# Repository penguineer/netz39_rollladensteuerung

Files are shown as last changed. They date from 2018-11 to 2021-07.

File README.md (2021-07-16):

# Rolladensteuerung

## Content

- controller:       Relais-Controller Rollläden
- manuellsteuerung: Schalter für Manuellbetrieb Rollläden
- raspberry:        Software für den Kontroll-Raspy
- relaiskarte:      Relais Rollläden
- switchboard:      Altes Schalterboard
- tuer-controller:  I2C-Bridge zur Tür-Steuerung
- tuer-steuerung:   Kontrolle Motor und Türstatus-Schalter
- wd-switch:        Watchdog-Switch für Reset per Raspy-

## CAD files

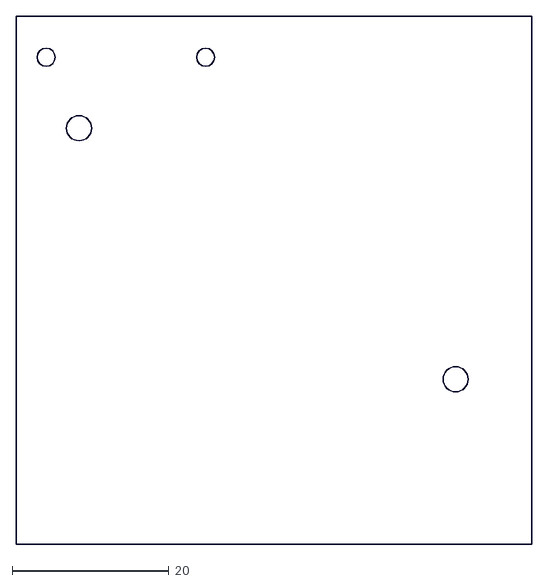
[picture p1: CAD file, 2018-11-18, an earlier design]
tuer-steuerung/converted_old/tuer-steuerung-dim.dxf
65.7 x 67.3

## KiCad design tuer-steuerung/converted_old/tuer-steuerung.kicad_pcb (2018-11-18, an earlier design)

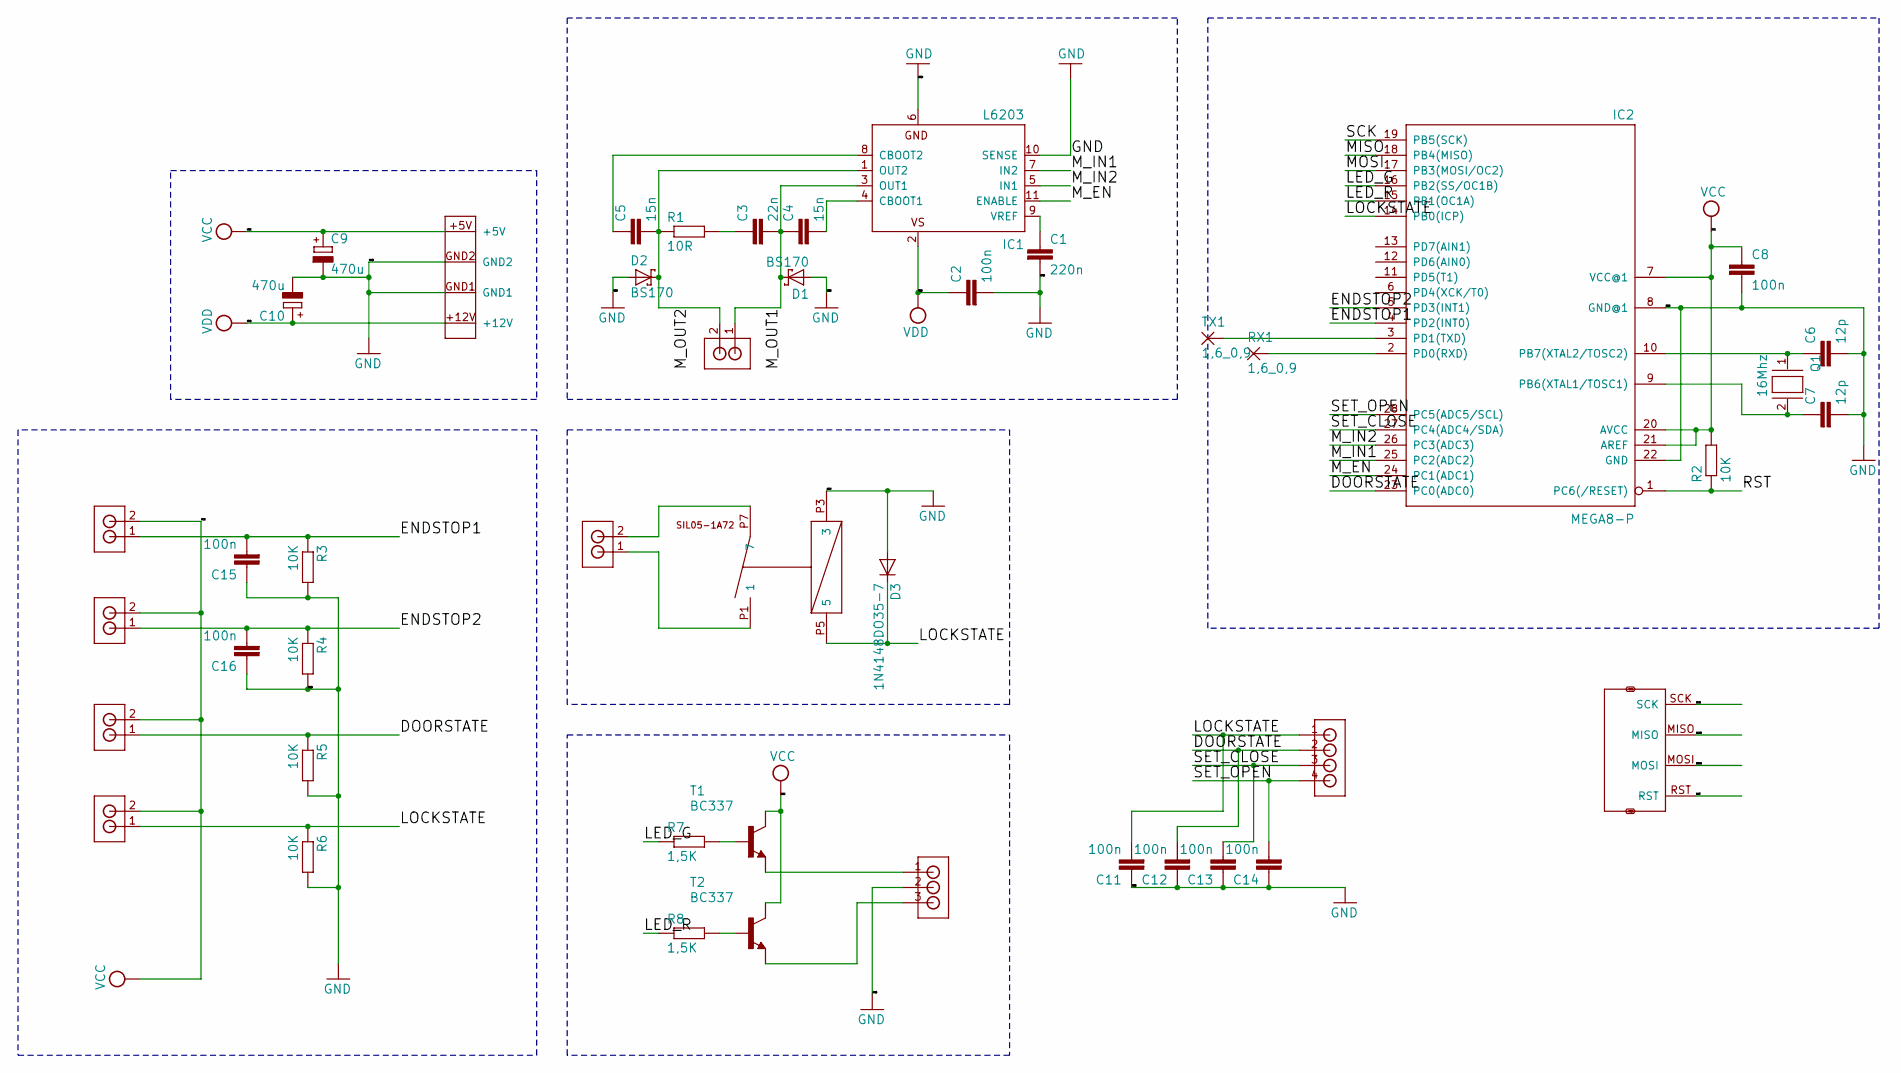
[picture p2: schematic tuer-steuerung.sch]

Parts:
C1: 220n; C025-024X044
C2, C8, C11, C12, C13, C14, C15, C16: 100n; C025-024X044
C3: 22n; C025-024X044
C4: 15n; C025-024X044
C5: 15n; C050-024X044
C6, C7: 12p; C050-025X075
C9, C10: 470u; TAP5-80
D1, D2: BS170; DO35-7
D3: 1N4148DO35-7; DO35-7
DOORSTATE1: RIACON_101_2
ENDSTOP1, ENDSTOP2: RIACON_101_2
IC1: L6203; MULTIWATT-11
IC2: MEGA8-P; DIL28-3
LOCKSTATE1: RIACON_101_2
MOTOR1: RIACON_101_2
NERDSTERN1: RIACON_101_2
Q1: 16Mhz; QS
R1: 10R; 0207_5V
R2, R3, R4, R5, R6: 10K; 0204_5
R7, R8: 1,5K; 0204_5
RX1: 1,6_0,9
T1, T2: BC337; TO92
TX1: 1,6_0,9
U$1: PSW_5
U$2: SIL05-1A72
U$3: AVR_ISP
U$4: RIACON_101_3
U$5: RIACON_101_4

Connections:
/DOORSTATE: C12.2, DOORSTATE1.1, IC2.23 (PC0(ADC0)), R5.1, U$5.2
/ENDSTOP1: C15.2, ENDSTOP1.1, IC2.4 (PD2(INT0)), R3.1
/ENDSTOP2: C16.2, ENDSTOP2.1, IC2.5 (PD3(INT1)), R4.1
/LED_G: IC2.16 (PB2(SS/OC1B)), R7.1
/LED_R: IC2.15 (PB1(OC1A)), R8.1
/LOCKSTATE: C11.2, D3.C, IC2.14 (PB0(ICP)), LOCKSTATE1.1, R6.1, U$2.P5 (5), U$5.1
/MISO: IC2.18 (PB4(MISO)), U$3.MISO
/MOSI: IC2.17 (PB3(MOSI/OC2)), U$3.MOSI
/M_EN: IC1.11 (ENABLE), IC2.24 (PC1(ADC1))
/M_IN1: IC1.7 (IN2), IC2.25 (PC2(ADC2))
/M_IN2: IC1.5 (IN1), IC2.26 (PC3(ADC3))
/M_OUT1: C3.2, C4.1, D1.C, IC1.3 (OUT1), MOTOR1.1
/M_OUT2: C5.2, D2.C, IC1.1 (OUT2), MOTOR1.2, R1.1
/RST: IC2.1 (PC6(/RESET)), R2.1, U$3.RST
/SCK: IC2.19 (PB5(SCK)), U$3.SCK
/SET_CLOSE: C13.2, IC2.27 (PC4(ADC4/SDA)), U$5.3
/SET_OPEN: C14.2, IC2.28 (PC5(ADC5/SCL)), U$5.4
GND: C1.2, C2.2, C6.2, C7.2, C8.2, C9.-, C10.-, C11.1, C12.1, C13.1, C14.1, C15.1, C16.1, D1.A, D2.A, D3.A, IC1.6 (GND), IC1.10 (SENSE), IC2.8 (GND@1), IC2.22 (GND), R3.2, R4.2, R5.2, R6.2, U$1.GND1, U$1.GND2, U$2.P3 (3), U$3.GND, U$4.2
unnamed: C1.1, IC1.9 (VREF)
unnamed: C3.1, R1.2
unnamed: C4.2, IC1.4 (CBOOT1)
unnamed: C5.1, IC1.8 (CBOOT2)
unnamed: C6.1, IC2.10 (PB7(XTAL2/TOSC2)), Q1.1
unnamed: C7.1, IC2.9 (PB6(XTAL1/TOSC1)), Q1.2
unnamed: IC2.2 (PD0(RXD)), RX1.1
unnamed: IC2.3 (PD1(TXD)), TX1.1
unnamed: NERDSTERN1.1, U$2.P1 (1)
unnamed: NERDSTERN1.2, U$2.P7 (7)
unnamed: R7.2, T1.2 (B)
unnamed: R8.2, T2.2 (B)
unnamed: T1.1 (E), U$4.1
unnamed: T2.1 (E), U$4.3
VCC: C8.1, C9.+, DOORSTATE1.2, ENDSTOP1.2, ENDSTOP2.2, IC2.7 (VCC@1), IC2.20 (AVCC), IC2.21 (AREF), LOCKSTATE1.2, R2.2, T1.3 (C), T2.3 (C), U$1.+5V, U$3.VCC
VDD: C2.1, C10.+, IC1.2 (VS), U$1.+12V

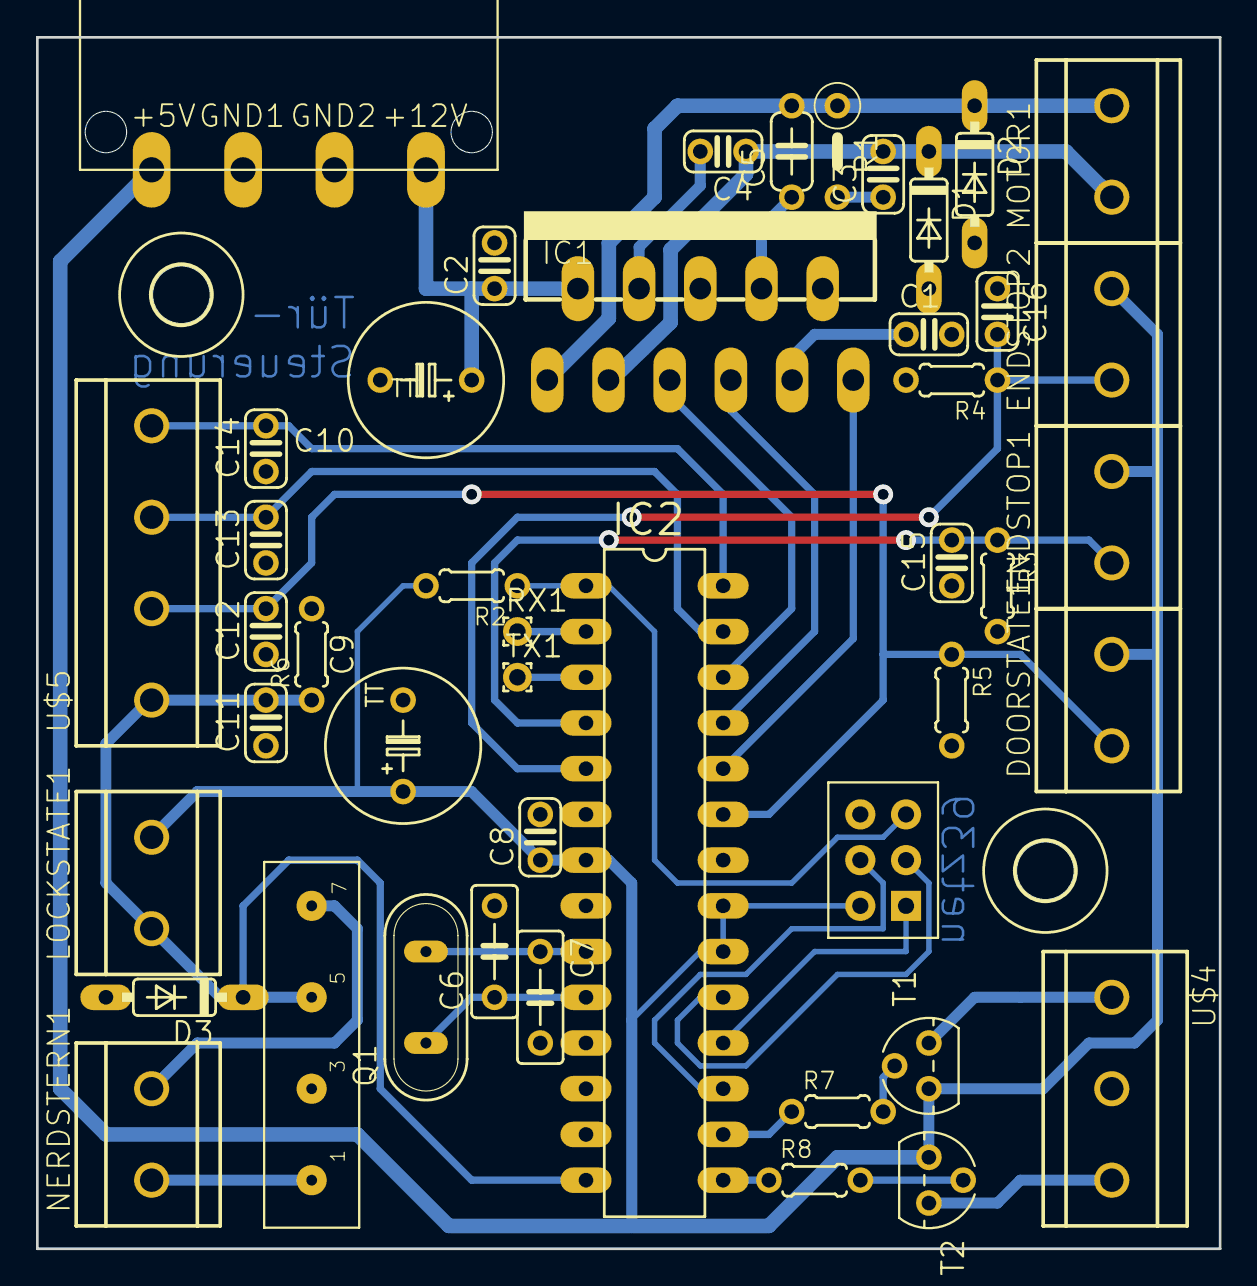
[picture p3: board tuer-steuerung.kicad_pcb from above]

Board: 2 copper layers, 65.7 x 67.3 mm, 47 parts (0 on the bottom side), 34 nets.

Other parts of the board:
U$6, U$7: 3,2

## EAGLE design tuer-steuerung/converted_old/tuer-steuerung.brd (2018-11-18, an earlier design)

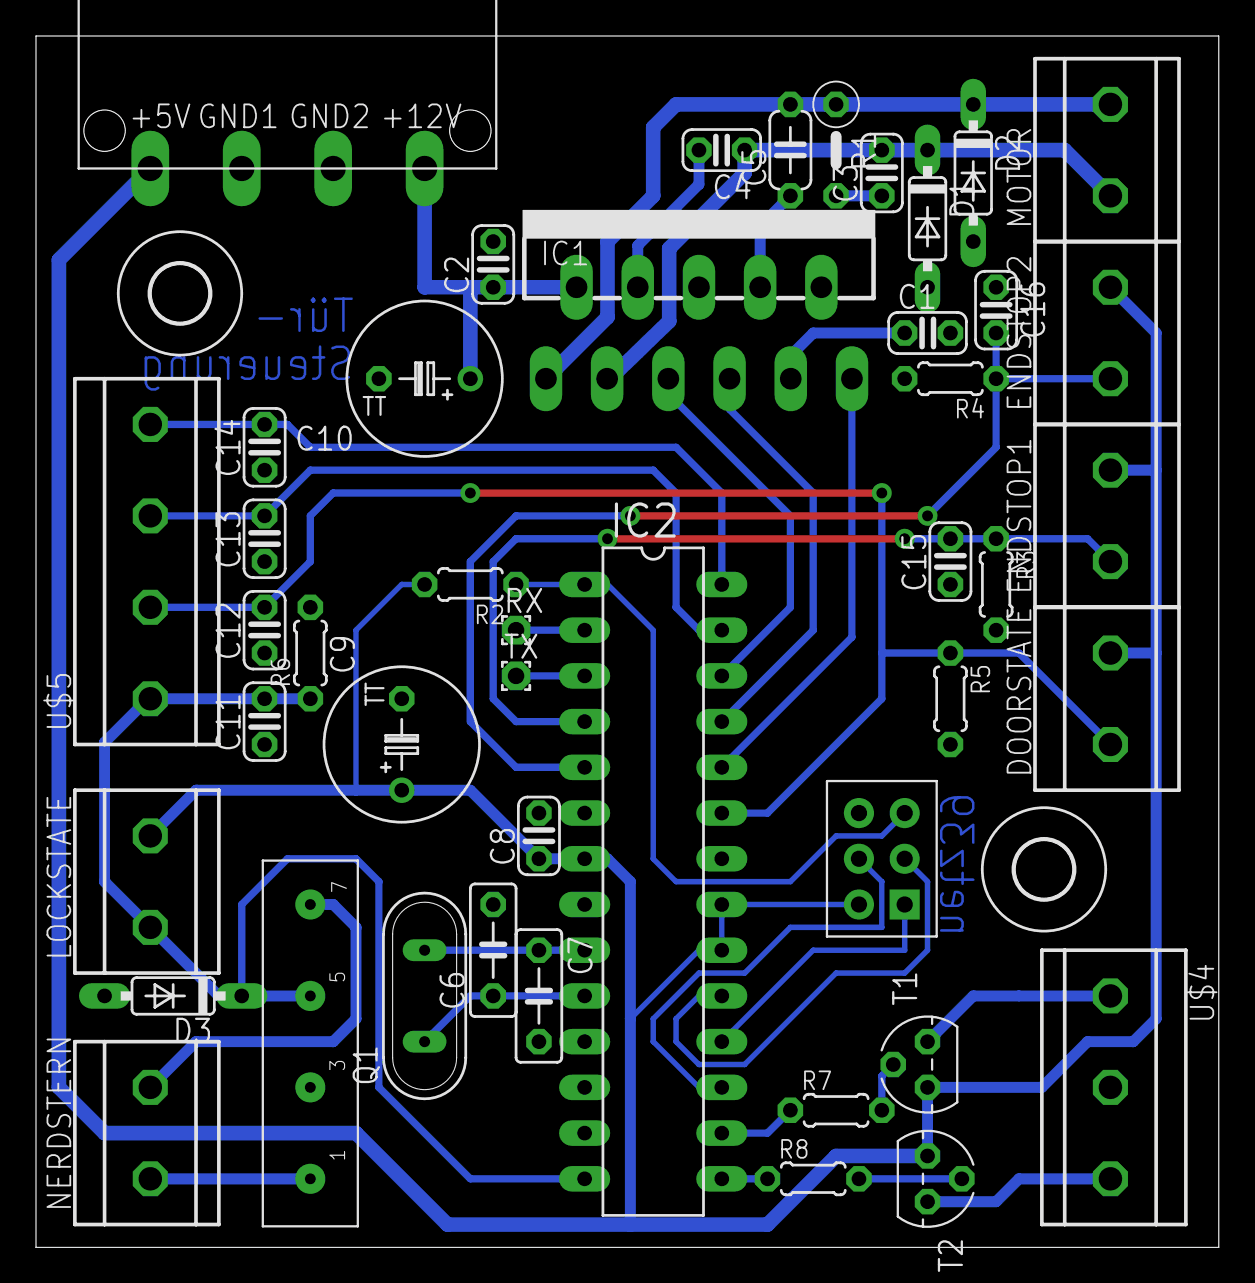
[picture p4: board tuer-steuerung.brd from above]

Board: 2 copper layers, 65.7 x 67.3 mm, 47 parts (0 on the bottom side), 34 nets.

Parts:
C1: 220n; C025-024X044
C2, C8, C11, C12, C13, C14, C15, C16: 100n; C025-024X044
C3: 22n; C025-024X044
C4: 15n; C025-024X044
C5: 15n; C050-024X044
C6, C7: 12p; C050-025X075
C9, C10: 470u; TAP5-80
D1, D2: BS170; DO35-7
D3: 1N4148DO35-7; DO35-7
DOORSTATE: RIACON_101_2
ENDSTOP1, ENDSTOP2: RIACON_101_2
IC1: L6203; MULTIWATT-11
IC2: MEGA8-P; DIL28-3
LOCKSTATE: RIACON_101_2
MOTOR: RIACON_101_2
NERDSTERN: RIACON_101_2
Q1: 16Mhz; QS
R1: 10R; 0207/5V
R2, R3, R4, R5, R6: 10K; 0204/5
R7, R8: 1,5K; 0204/5
RX: 1,6/0,9
T1, T2: BC337; TO92
TX: 1,6/0,9
U$1: PSW_5
U$2: SIL05-1A72
U$3: AVR_ISP
U$4: RIACON_101_3
U$5: RIACON_101_4
U$6, U$7: 3,2

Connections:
DOORSTATE: C12.2, DOORSTATE.1, IC2.23, R5.1, U$5.2
ENDSTOP1: C15.2, ENDSTOP1.1, IC2.4, R3.1
ENDSTOP2: C16.2, ENDSTOP2.1, IC2.5, R4.1
GND: C1.2, C2.2, C6.2, C7.2, C8.2, C9.-, C10.-, C11.1, C12.1, C13.1, C14.1, C15.1, C16.1, D1.A, D2.A, D3.A, IC1.6, IC1.10, IC2.8, IC2.22, R3.2, R4.2, R5.2, R6.2, U$1.GND1, U$1.GND2, U$2.P3, U$3.GND, U$4.2
LED_G: IC2.16, R7.1
LED_R: IC2.15, R8.1
LOCKSTATE: C11.2, D3.C, IC2.14, LOCKSTATE.1, R6.1, U$2.P5, U$5.1
MISO: IC2.18, U$3.MISO
MOSI: IC2.17, U$3.MOSI
M_EN: IC1.11, IC2.24
M_IN1: IC1.7, IC2.25
M_IN2: IC1.5, IC2.26
M_OUT1: C3.2, C4.1, D1.C, IC1.3, MOTOR.1
M_OUT2: C5.2, D2.C, IC1.1, MOTOR.2, R1.1
unnamed: C6.1, IC2.10, Q1.1
unnamed: C7.1, IC2.9, Q1.2
unnamed: C1.1, IC1.9
unnamed: NERDSTERN.2, U$2.P7
unnamed: NERDSTERN.1, U$2.P1
unnamed: C3.1, R1.2
unnamed: C4.2, IC1.4
unnamed: C5.1, IC1.8
unnamed: R7.2, T1.2
unnamed: R8.2, T2.2
unnamed: T1.1, U$4.1
unnamed: T2.1, U$4.3
unnamed: IC2.3, TX.1
unnamed: IC2.2, RX.1
RST: IC2.1, R2.1, U$3.RST
SCK: IC2.19, U$3.SCK
SET_CLOSE: C13.2, IC2.27, U$5.3
SET_OPEN: C14.2, IC2.28, U$5.4
VCC: C8.1, C9.+, DOORSTATE.2, ENDSTOP1.2, ENDSTOP2.2, IC2.7, IC2.20, IC2.21, LOCKSTATE.2, R2.2, T1.3, T2.3, U$1.+5V, U$3.VCC
VDD: C2.1, C10.+, IC1.2, U$1.+12V

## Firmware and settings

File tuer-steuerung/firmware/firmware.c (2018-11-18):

/*
 * Tür-Steuerung
 * Autor: Stefan Haun <tux@netz39.de>
 * 
 * Entwickelt für ATMEGA8
 * 
 * DO NOT forget to set the fuses s.th. the controller uses a 16 MHz external oscillator clock!
 */


/* define CPU frequency in MHz here if not defined in Makefile */
#ifndef F_CPU
#define F_CPU 16000000UL
#endif

#include <avr/io.h>
#include <avr/interrupt.h>
#include <util/delay.h>
#include <stdint.h>


/// Port Helper Macros
#define setPortB(mask)   (PORTB |= (mask))
#define resetPortB(mask) (PORTB &= ~(mask))
#define setPortC(mask)   (PORTC |= (mask))
#define resetPortC(mask) (PORTC &= ~(mask))
#define setPortD(mask)   (PORTD |= (mask))
#define resetPortD(mask) (PORTD &= ~(mask))

/// Eingänge

// Endstop-Schalter
#define isEndstopClose   (((PIND & (1<<PD2)) == (1<<PD2)) ? 1 : 0)
#define isEndstopOpen    (((PIND & (1<<PD3)) == (1<<PD3)) ? 1 : 0)

// Command-Eingänge (invertiert!)
#define isSetClose       (((PINC & (1<<PC4)) == (1<<PC4)) ? 0 : 1)
#define isSetOpen        (((PINC & (1<<PC5)) == (1<<PC5)) ? 0 : 1)

// Türschloss
#define isLockOpen       (((PINB & (1<<PB0)) == (1<<PB0)) ? 1 : 0)

// Türstatus
#define isDoorClosed     (((PINC & (1<<PC0)) == (1<<PC0)) ? 1 : 0)


/// Motor-Funktionen

// Status Motor-Ansteuerung zurückgeben
#define isHBridgeActive  (((PINC & (1<<PC1)) == (1<<PC1)) ? 1 : 0)
#define isMotorOpen      (((PINC & (1<<PC2)) == (1<<PC2)) ? 1 : 0)
#define isMotorClose     (((PINC & (1<<PC3)) == (1<<PC3)) ? 1 : 0)

/*
 * Block-Counter für den Motor.
 * Wird vom Timer decrementiert. Nur wenn == 0 kann das Schloss abgeschlossen
 * werden.
 */
static char isBlocked = 0;

/*
 * Motor anhalten!
 */
void stopMotor() {
  resetPortC((1 << PC2) | (1 << PC3));
  // aktives Bremsen passiert nur, wenn die H-Brücke aktiviert ist
  // -> Enable 250ms später löschen
  _delay_ms(250);
  resetPortC((1 << PC1));
}

/*
 * Motor für einen bestimmten Zeitraum blockieren.
 */
void blockMotor() {
  isBlocked = 100;
}

/*
 * Motor-Stellung und Schalter prüfen, ggf. Motor stoppen.
 */
void checkMotor() {
  // Fall: Motor "auf"
  if (isMotorOpen) {
    // Motor darf nur "auf" drehen, wenn der Auf-Endstop nicht erreicht ist
    if (isEndstopOpen)
      stopMotor();
  }
  
  // Fall: Motor "zu"
  if (isMotorClose) {
    // schließen nur bei geschlossener Tür
    if (!isDoorClosed || isBlocked)
      stopMotor();
    
    // Motor darf nur "zu" drehen, wenn der Zu-Endstop nicht erreicht ist
    if (isEndstopClose)
      stopMotor();
    
    // fertig, wenn das Schloss nicht mehr offen ist
    if (!isLockOpen)
      stopMotor();    
  }  
}

/*
 * Motor starten
 * direction      Drehrichtung "zu" oder "auf"
 * siehe Konstanten unter diesem Kommentar
 */
#define MOTOR_CLOSE 1
#define MOTOR_OPEN  2
void startMotor(const char direction) {
  // Motor Close
  if (direction == MOTOR_CLOSE) {
    // endstop close darf nicht aktiv sein, Schloss muss offen sein und Tür muss geschlossen sein
    if (!isEndstopClose && isLockOpen && isDoorClosed && !isBlocked) {
      // Richtung einstellen
      resetPortC(1 << PC2);
      setPortC(1 << PC3);
      // H-Brücke aktivieren
      setPortC(1 << PC1);
    }
  }

  // Motor Open
  if (direction == MOTOR_OPEN) {
    // endstop open darf nicht aktiv sein
    if (!isEndstopOpen) {
      // Richtung einstellen
      resetPortC(1 << PC3);
      setPortC(1 << PC2);
      // H-Brücke aktivieren
      setPortC(1 << PC1);
    }
  }

  // abschließender Check
  checkMotor();
}


/// Anzeige-Funktionen (LED)

// Status
/*
 * Bits 0,1 rot
 * Bits 2,3 grün
 */

#define LED_OFF  0b00
#define LED_SLOW 0b01
#define LED_FAST 0b10
#define LED_ON   0b11

#define GET_RED     (LEDstatus & 0b0011)
#define GET_GREEN   ((LEDstatus & 0b1100) >> 2)

static char LEDstatus = 0;

/*
 * Farbanzeige (LED) setzen oder löschen
 * 
 * col      Farbe
 * state    Status an/aus
 * siehe Konstanten unter diesem Kommentar
 */
#define COL_RED   1
#define COL_GREEN 2
#define COL_OFF   0
#define COL_ON    1
void color(const char col, const char state) {
  const char mask = 1 << (col);
  if (state)
    setPortB(mask);
  else
    resetPortB(mask);
}

void setLED(const char col, const char state) {
  if (col == COL_RED) {
    LEDstatus &= ~(0b0011);
    LEDstatus |= state;
  }
  if (col == COL_GREEN) {
    LEDstatus &= ~(0b1100);
    LEDstatus |= (state<<2);
  }
}

/// Zustand

/*
 * Prüfen, ob das Schloss komplett geöffnet ist
 * Return: 0, wenn noch nicht komplett geöffnet, sonst ungleich 0
 */
char isFullyOpen() {
  // komplett geöffnet, wenn der Endstop erreicht ist
  return isEndstopOpen;
}

/*
 * Prüfen, ob das Schloss komplett geschlossen ist
 * Return: 0, wenn noch nicht komplett geschlossen, sonst ungleich 0
 */
char isFullyClosed() {
  // komplett geschlossen, wenn der Endstop erreicht 
  // oder das Schloss nicht mehr offen ist
  return isEndstopClose || !isLockOpen;
}


/// Infrastruktur

void init(void) {
  /*
   * Pin-Config PortB:
   *   PB0: IN	Lockstate
   *   PB1: OUT	LED_R
   *   PB2: OUT LED_G
   *   PB3: MOSI
   *   PB4: MISO
   *   PB5: SCK
   * 
   * Pin-Config PortC:
   *   PC0: IN	Doorstate
   *   PC1: OUT	M_EN (Motor enable)
   *   PC2: OUT	M_IN1 (Motor Input direction 1)
   *   PC3: OUT	M_IN2 (Motor Input direction 2)
   *   PC4: IN	SET_CLOSE
   *   PC5: IN	SET_OPEN
   * 
   * Pin-Config PortD:
   *   PD0: RXD
   *   PD1; TXD
   *   PD2: IN	Endstop 1, Closed (INT0)
   *   PD3: IN	Endstop 2, Open   (INT1)
   */
  
  DDRB  = 0b00000110;
  // PullUp für Eingänge
  PORTB = 0b00000000;

  DDRC  = 0b00001110;
  // PullUp für Eingänge
  PORTC = 0b00110000;

  DDRD  = 0b00000000;
  // PullUp für Eingänge
  PORTD = 0b00000000;

   /*  disable interrupts  */
   cli();
   
   // Interrupts einstellen
   // interrupt bei Pegelwechsel
   
   // PD2 -> INT0
   MCUCR |= (1 << ISC00); // | (1 << ISC01);
   // PD3 -> INT1
   MCUCR |= (1 << ISC10); // | (1 << ISC11);
   
   // aktivieren
   GICR |= (1 << INT0) | (1 << INT1);

   
   /*  set clock   */
  
  // prescaler 1024, CTC
  TCCR1A = 0;
  TCCR1B = (1 << WGM12) | (1 << CS02) | (1 << CS00);

  // vergleichswert
  OCR1A = 0xff;
  
  // aktivieren
  TIMSK |= (1 << OCIE1A);
    
  
  
  // Global Interrupts aktivieren
  sei();  
}

int main(void)
{
  // initialisieren
  init();

  // Bereit-Meldung
  _delay_ms(250);
  setLED(COL_RED, LED_FAST);
  _delay_ms(1000);
  setLED(COL_RED, LED_OFF);
  setLED(COL_GREEN, LED_FAST);
  _delay_ms(700);
  setLED(COL_GREEN, LED_OFF);
  
  
  while(1) {
    checkMotor();

    // bei offener Tür immer auch das Schloss öffnen!
    if (!isDoorClosed && !isFullyOpen()) {
      startMotor(MOTOR_OPEN);
      blockMotor();
    }
    else if (isSetOpen) {
      startMotor(MOTOR_OPEN);
    }
    else if (isSetClose) {
      startMotor(MOTOR_CLOSE);
    } else if (!isDoorClosed && !isFullyOpen()) {
      // bei unklarem Status: tür auf
      startMotor(MOTOR_OPEN);
    }
  
    // Es wird nur einer der Stati rot/grün angezeigt, 
    // wenn die Tür "geschlossen" signalisiert, wird rot bevorzugt,
    // bei gleichzeitigem "offen"-status blinkt grün schnell
    // (dann liegt ein unzulässiger Zustand vor).

    // grün blinken, wenn Motor Richtung "auf"
    if (isMotorOpen)
      setLED(COL_GREEN, LED_SLOW);
    // grün, wenn komplett offen, sonst aus
    else if (isFullyOpen())
      setLED(COL_GREEN, isFullyClosed() ? LED_FAST : LED_ON);
//      setLED(COL_GREEN, isFullyClosed() ? LED_OFF : LED_ON);
    else
      setLED(COL_GREEN, LED_OFF);
    
    // rot blinken, wenn Motor Richtung "zu"
    if (isMotorClose)
      setLED(COL_RED, LED_SLOW);
    // rot, wenn komplett geschlossen, sonst aus
    else
      setLED(COL_RED, isFullyClosed() ?  LED_ON : LED_OFF);
  
    
    
  } // while
  
  return 0;
}



/// Interrupt-Vektoren

volatile uint8_t blink = 0;
volatile uint8_t phase = 0;
ISR (TIMER1_COMPA_vect)
{
  // store state and disable interrupts
  const uint8_t _sreg = SREG;
  cli();
  
  // decrease the motor block counter
  if ((isBlocked > 0) && isDoorClosed)
    isBlocked--;

  // another motor check here
  checkMotor();
  
  // LED setting

  // red led
  const char rst = GET_RED;
  
  if (rst == LED_ON)
    color(COL_RED, COL_ON);
  else if (rst == LED_OFF)
    color(COL_RED, COL_OFF);

  // green led
  const char gst = GET_GREEN;
  if (gst == LED_ON)
    color(COL_GREEN, COL_ON);
  else if (gst == LED_OFF)
    color(COL_GREEN, COL_OFF);

  // anything blinking
  blink++;
  if (blink > 10) {
    blink = 0;
    phase++;
  
    if (phase > 3)
      phase = 0;

    if (rst == LED_SLOW)
      color(COL_RED, phase>1);
    else if (rst == LED_FAST)
      color(COL_RED, phase%2);
  
    if (gst == LED_SLOW)
      color(COL_GREEN, phase>1);
    else if (gst == LED_FAST)
      color(COL_GREEN, phase%2);
  } // blink


  // restore state
  SREG = _sreg;  
}

ISR (INT0_vect) {
  // store state and disable interrupts
  const uint8_t _sreg = SREG;
  cli();
    
  checkMotor();

  // restore state
  SREG = _sreg;
}

ISR (INT1_vect) {
  // store state and disable interrupts
  const uint8_t _sreg = SREG;
  cli();

  checkMotor();

  // restore state
  SREG = _sreg;
}

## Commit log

2018-11-18 Converted eagle pcb and schematic to kicad, moved to converted_old
    [tuer-steuerung-dim.dxf, tuer-steuerung.brd, tuer-steuerung.kicad_pcb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]
2018-11-18 added l6203 motor driver footprint, symbol
2018-11-18 Added many schematic sheets with basic structure and many todo texts
    [5vFilter.sch, display.sch, external.sch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]
2018-11-22 Remove KiCAD backup files
    Fixes: 8c04058d9f3fa0f4235e588c12f971bd110264bf
2018-11-22 Revise Git ignore lists
    * split up into per folder
    * use special KiCAD ignore list from https://github.com/github/gitignore
    Suggested-by: David Kilias <david.kilias@gmail.com>
2020-08-18 Imported updated requirements for new door pcb
    [display.sch, external.sch, motor.sch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]
